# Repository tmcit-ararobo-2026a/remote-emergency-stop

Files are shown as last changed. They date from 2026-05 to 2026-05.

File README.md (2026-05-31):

# Remote Emergency Stop

ロボットなどの遠隔非常停止
920MHzの通信可能

## 目次

1. [概要](#1-概要)
2. [ドキュメント](#2-ドキュメント)
3. [ビルド・使い方](#3-ビルド使い方)
4. [システム構成](#4-システム構成)
5. [ライセンス](#5-ライセンス)

## 1. 概要

<!-- プロジェクトの目的・背景・解決する課題を記述 -->

## 2. ドキュメント

| ドキュメント | 説明 |
| :-: | :-: |
| [CONTRIBUTING.md](./CONTRIBUTING.md) | 開発フロー・コミット規約・コーディング規約 |
| [docs/coding-rules.md](./docs/coding-rules.md) | コーディング規約の詳細 |
| [docs/uml/](./docs/uml/) | UML図 |

## 3. ビルド・使い方

<!-- ビルドのやり方 -->
<!-- 使い方 -->

## 4. システム構成

<!-- ROS2ノード構成・STM32との通信方式・ハードウェア構成 等 -->
<!-- 依存クラスが3つ以上ある場合は docs/uml/ にUML図を作成し、ここにリンクする -->

## 5. ライセンス

本リポジトリは [MITライセンス](./LICENSE) のもとで公開されています。

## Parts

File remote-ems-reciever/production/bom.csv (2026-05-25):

Designator | Footprint | Quantity | Value | LCSC Part #
C1, C4 | 0603 | 2 | 4.7u
C10 | 0603 | 1 | 0.47u
C2, C3, C5, C6, C7, C8, C9 | 0603 | 7 | 0.1u
D1, D2, D3, D4 | 0603 | 4 | LED
IC1 | 114993121 | 1 | Wio-E5
IC2 | SOIC127P600X175-8N | 1 | MCP2562
J1 | SMA_Molex_73251-2120_EdgeMount_Horizontal | 1 | Conn_Coaxial
J2, J3, J5 | JST_XH_S4B-XH-A_1x04_P2.50mm_Horizontal | 3 | Conn_01x04
J4 | PinHeader_1x04_P2.54mm_Vertical | 1 | Conn_01x04_Pin
JP1 | TestPoint_2Pads_Pitch2.54mm_Drill0.8mm | 1 | Jumper_2_Open
Q1 | SOT-23 | 1 | BSS138
R1, R10, R5, R9 | 0603 | 4 | 10k
R11 | 0603 | 1 | 100
R2 | 0603 | 1 | 120
R3, R6, R7, R8 | 0603 | 4 | 1k
R4 | 0603 | 1 | 470
SW1, SW2, SW3 | switch_TVAF06-A020B-R | 3 | SW_Push
SW4 | SW_DIP_SPSTx02_Slide_9.78x7.26mm_W7.62mm_P2.54mm | 1 | SW_DIP_x02
U1 | LQFP-32_7x7mm_P0.8mm | 1 | STM32G431K8Tx
U2 | SOT-23-5_HandSoldering | 1 | NJM12888F33

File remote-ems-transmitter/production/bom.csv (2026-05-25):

Designator | Footprint | Quantity | Value | LCSC Part #
BAR1 | OSX05201-GGR1 | 1 | OSX05201-GGR1
BAR2 | OSX40601-AO | 1 | OSX40601-AO
BT1 | JST_PH_B2B-PH-K_1x02_P2.00mm_Vertical | 1 | Battery_Cell
C1, C4, C8, C9 | 0603 | 4 | 4.7u
C10, C2, C3, C5, C6, C7 | 0603 | 6 | 0.1u
C11 | 0603 | 1 | 0.47u
C12, C13, C14, C15 | 0603 | 4 | 0.1uf
D1, D2 | LED_D5.0mm_FlatTop | 2 | LED
D3 | 0603 | 1 | LED
F1 | 355715 | 1 | Fuse
IC1 | 114993121 | 1 | Wio-E5
J1 | PinHeader_1x04_P2.54mm_Vertical | 1 | Conn_01x04_Pin
J2, J3 | JST_XH_B2B-XH-A_1x02_P2.50mm_Vertical | 2 | Conn_01x02
J4 | SMA_Molex_73251-2120_EdgeMount_Horizontal | 1 | Conn_Coaxial
J5 | USB_C_Receptacle_HRO_TYPE-C-31-M-12 | 1 | USB_C_Receptacle_USB2.0
J6 | PinHeader_1x02_P2.54mm_Vertical | 1 | Conn_01x02_Pin
Q1, Q2 | SOT-23 | 2 | BSS138
R1, R2, R20, R22, R5, R6, R8 | 0603 | 7 | 10k
R10, R11, R12, R13, R14, R15, R16, R17, R18, R4, R9 | 0603 | 11 | 4.7k
R19 | 0603 | 1 | 2k
R21, R3 | 0603 | 2 | 100
R23 | 0603 | 1 | 1k
R7 | 0603 | 1 | 470
SW1, SW2, SW3 | switch_TVAF06-A020B-R | 3 | SW_Push
SW4 | 2MS1-T1-B4-VS2-Q-E-S | 1 | 2MS1-T2-B4-VS2-Q-E-S
U1 | LQFP-32_7x7mm_P0.8mm | 1 | STM32G431K8Tx
U2 | SOT-23-5 | 1 | MCP73831-2-OT
U3 | SOT-23-5_HandSoldering | 1 | NJM12888F33
U4, U5 | SOT-23-5_HandSoldering | 2 | XC8111AA01MR-G

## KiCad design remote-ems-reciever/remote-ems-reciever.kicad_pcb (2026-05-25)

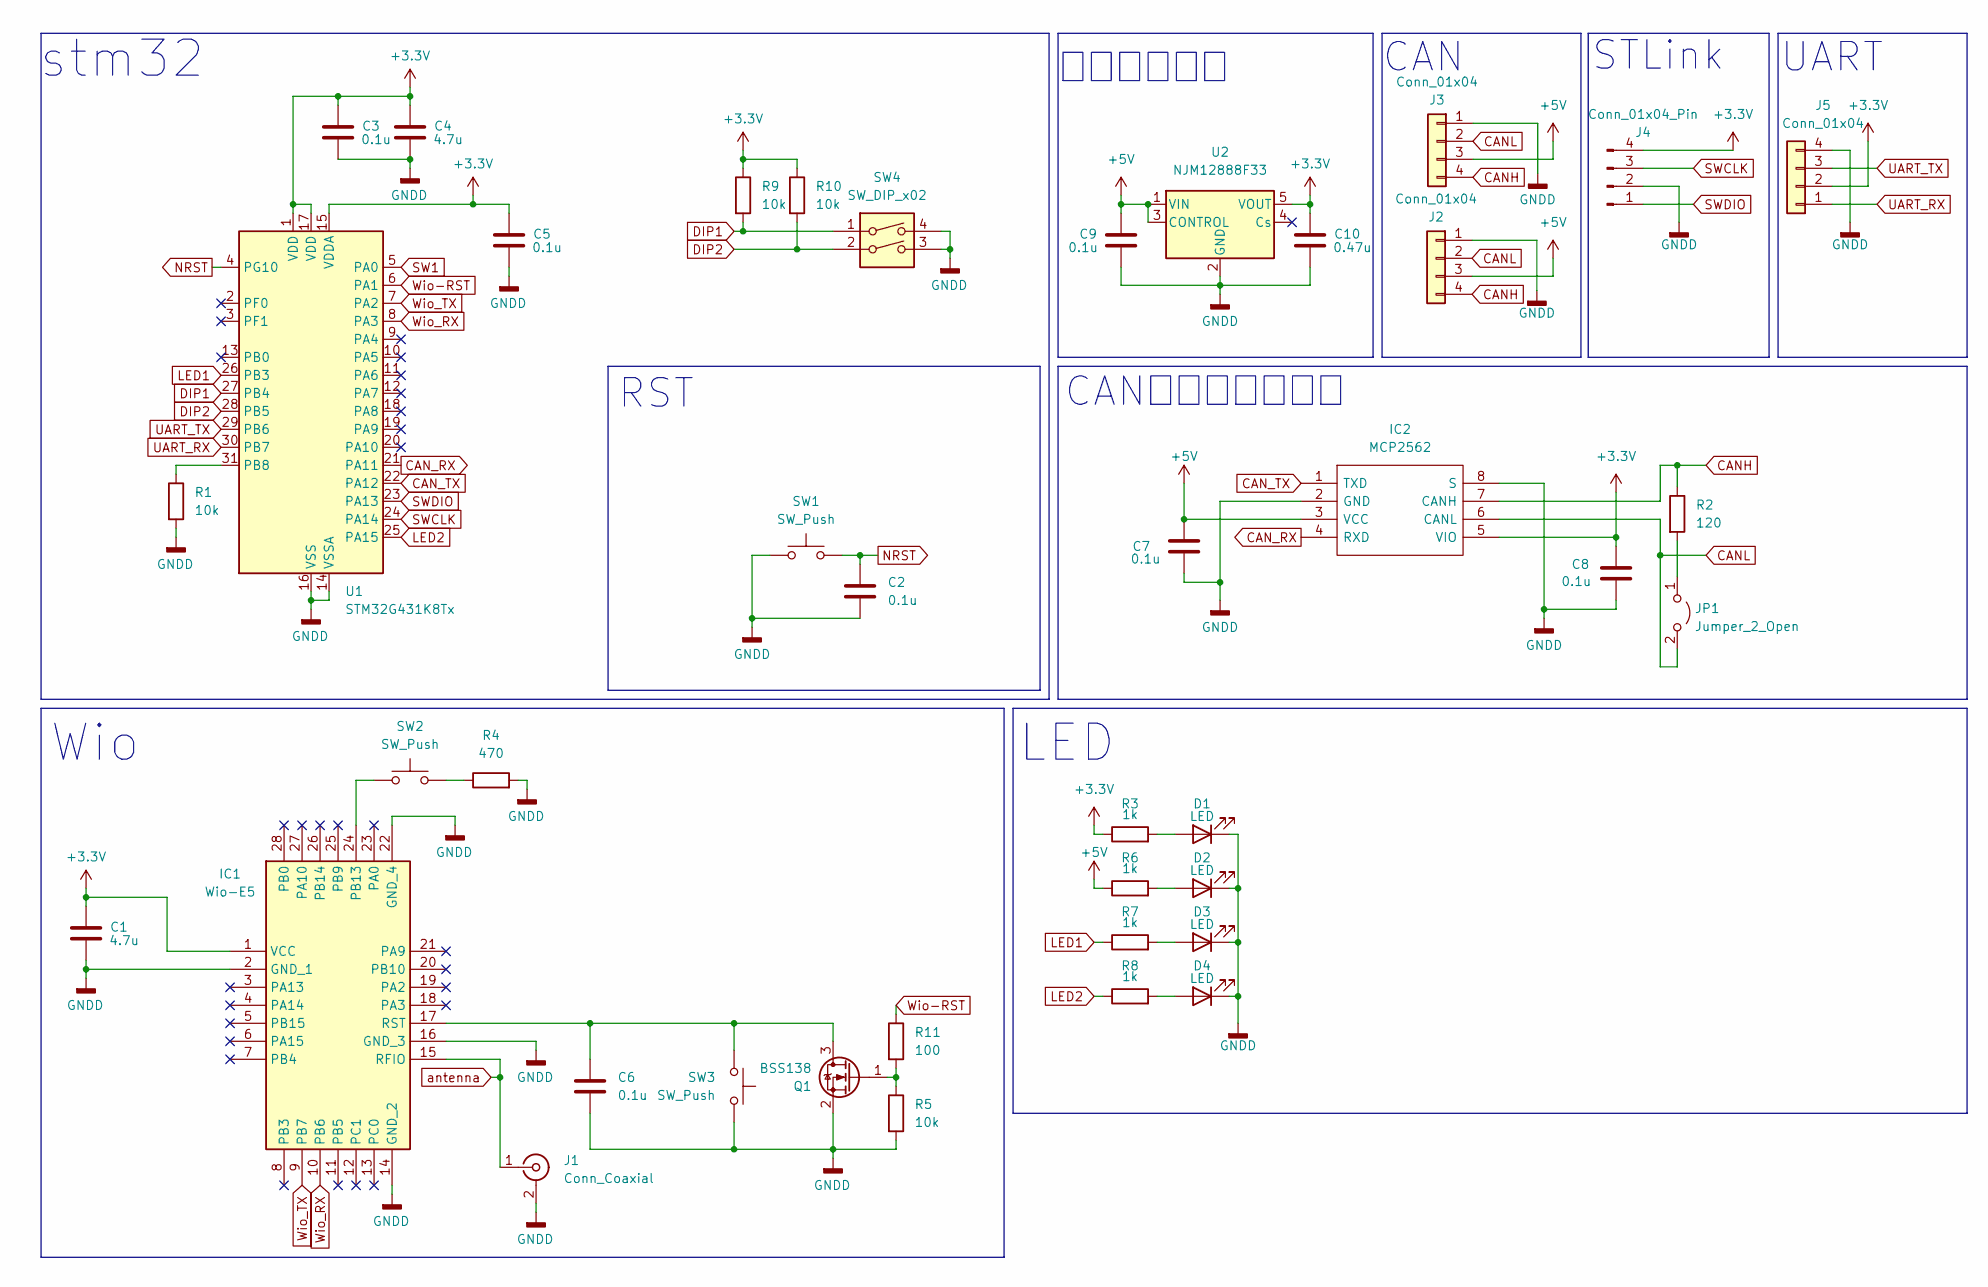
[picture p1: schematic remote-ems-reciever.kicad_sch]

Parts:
C1, C4: 4.7u; C_0603_1608Metric_Pad1.08x0.95mm_HandSolder
C2, C3, C5, C6, C7, C8, C9: 0.1u; C_0603_1608Metric_Pad1.08x0.95mm_HandSolder
C10: 0.47u; C_0603_1608Metric_Pad1.08x0.95mm_HandSolder
D1, D2, D3, D4: LED; LED_0603_1608Metric_Pad1.05x0.95mm_HandSolder
IC1: Wio-E5; 114993121; Mouser Part Number 713-114993121
IC2: MCP2562; SOIC127P600X175-8N; Mouser Part Number 771-TJA1441AT/0Z
J1: Conn_Coaxial; SMA_Molex_73251-2120_EdgeMount_Horizontal
J2, J3, J5: Conn_01x04; JST_XH_S4B-XH-A_1x04_P2.50mm_Horizontal
J4: Conn_01x04_Pin; PinHeader_1x04_P2.54mm_Vertical
JP1: Jumper_2_Open; TestPoint_2Pads_Pitch2.54mm_Drill0.8mm
Q1: BSS138; SOT-23
R1, R5, R9, R10: 10k; R_0603_1608Metric_Pad0.98x0.95mm_HandSolder
R2: 120; R_0603_1608Metric_Pad0.98x0.95mm_HandSolder
R3, R6, R7, R8: 1k; R_0603_1608Metric_Pad0.98x0.95mm_HandSolder
R4: 470; R_0603_1608Metric_Pad0.98x0.95mm_HandSolder
R11: 100; R_0603_1608Metric_Pad0.98x0.95mm_HandSolder
SW1, SW2, SW3: SW_Push; switch_TVAF06-A020B-R
SW4: SW_DIP_x02; SW_DIP_SPSTx02_Slide_9.78x7.26mm_W7.62mm_P2.54mm
U1: STM32G431K8Tx; LQFP-32_7x7mm_P0.8mm
U2: NJM12888F33; SOT-23-5_HandSoldering

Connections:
+3.3V: C1.1, C3.1, C4.1, C5.1, C8.1, C10.1, IC1.1 (VCC), IC2.5 (VIO), J4.4, J5.2, R3.1, R9.1, R10.1, U1.1 (VDD), U1.15 (VDDA), U1.17 (VDD), U2.5 (VOUT)
+5V: C7.1, C9.1, IC2.3 (VCC), J2.3, J3.3, R6.1, U2.1 (VIN), U2.3 (CONTROL)
CANH: IC2.7 (CANH), J2.4, J3.4, R2.1
CANL: IC2.6 (CANL), J2.2, J3.2, JP1.2 (B)
CAN_RX: IC2.4 (RXD), U1.21 (PA11)
CAN_TX: IC2.1 (TXD), U1.22 (PA12)
DIP1: R9.2, SW4.1, U1.27 (PB4)
DIP2: R10.2, SW4.2, U1.28 (PB5)
GNDD: C1.2, C2.2, C3.2, C4.2, C5.2, C6.2, C7.2, C8.2, C9.2, C10.2, D1.1 (K), D2.1 (K), D3.1 (K), D4.1 (K), IC1.2 (GND_1), IC1.14 (GND_2), IC1.16 (GND_3), IC1.22 (GND_4), IC2.2 (GND), IC2.8 (S), J1.2 (Ext), J2.1, J3.1, J4.2, J5.4, Q1.2 (S), R1.2, R4.2, R5.2, SW1.1, SW3.1, SW4.3, SW4.4, U1.14 (VSSA), U1.16 (VSS), U1.32 (VSS), U2.2 (GND)
LED1: R7.1, U1.26 (PB3)
LED2: R8.1, U1.25 (PA15)
NRST: C2.1, SW1.2, U1.4 (PG10)
unnamed: D1.2 (A), R3.2
unnamed: D2.2 (A), R6.2
unnamed: D3.2 (A), R7.2
unnamed: D4.2 (A), R8.2
unnamed: IC1.24 (PB13), SW2.2
unnamed: C6.1, IC1.17 (RST), Q1.3 (D), SW3.2
unnamed: JP1.1 (A), R2.2
unnamed: Q1.1 (G), R5.1, R11.2
unnamed: R4.1, SW2.1
unnamed: R1.1, U1.31 (PB8)
SW1: U1.5 (PA0)
SWCLK: J4.3, U1.24 (PA14)
SWDIO: J4.1, U1.23 (PA13)
UART_RX: J5.1, U1.30 (PB7)
UART_TX: J5.3, U1.29 (PB6)
Wio-RST: R11.1, U1.6 (PA1)
Wio_RX: IC1.10 (PB6), U1.8 (PA3)
Wio_TX: IC1.9 (PB7), U1.7 (PA2)
antenna: IC1.15 (RFIO), J1.1 (In)

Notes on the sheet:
CAN
Wio
RST
CANトランシーバー
レギュレータ
UART
stm32
LED
STLink

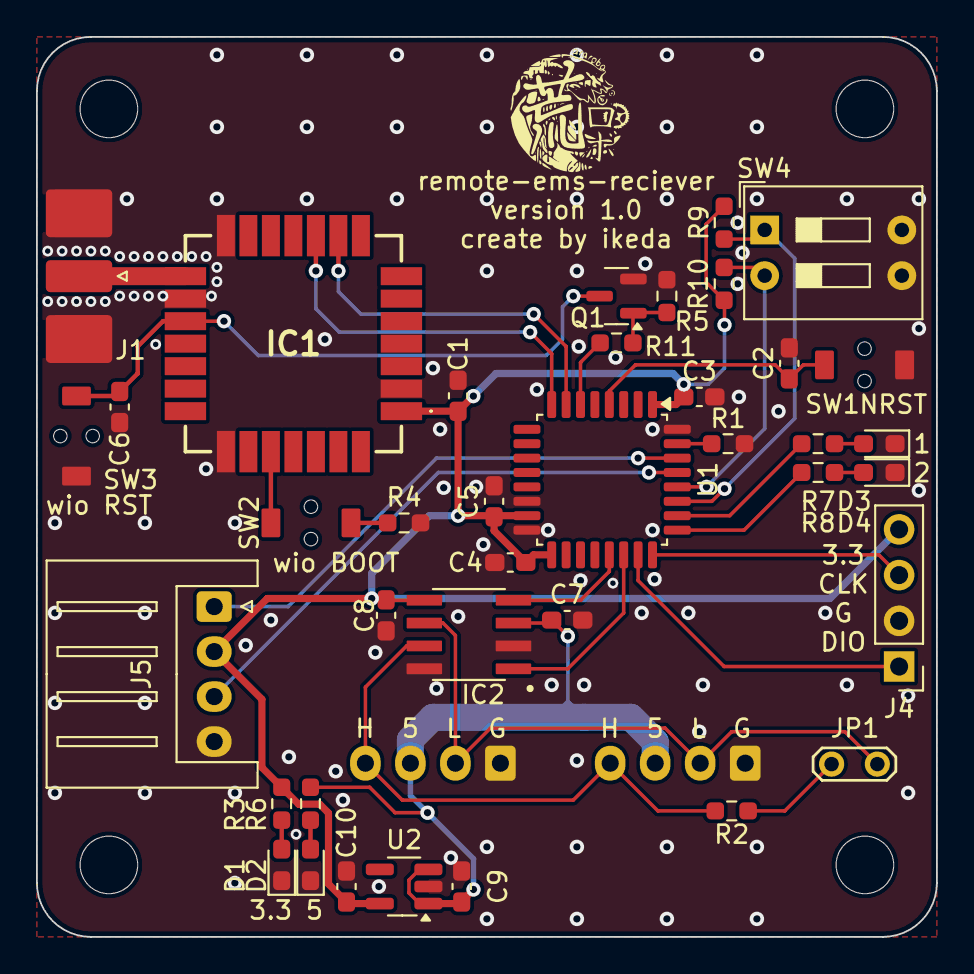
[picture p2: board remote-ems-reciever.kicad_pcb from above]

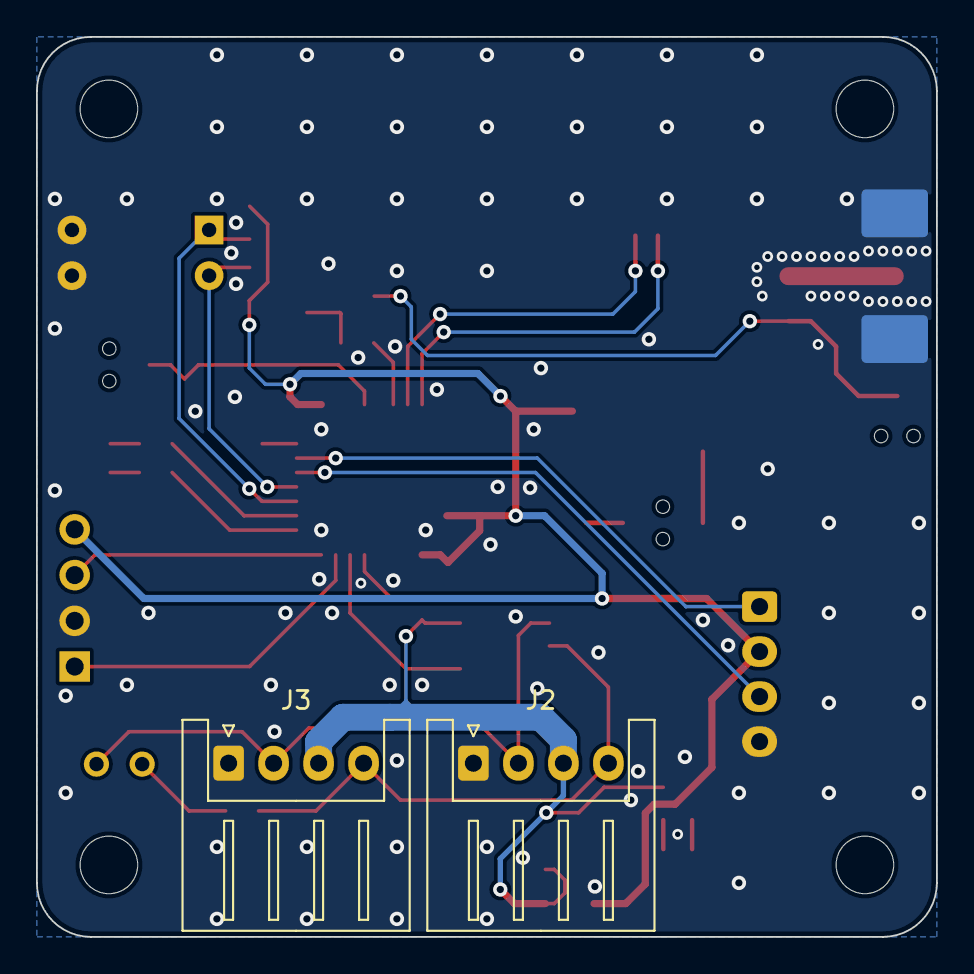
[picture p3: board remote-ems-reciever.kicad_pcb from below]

Board: 2 copper layers, 50.0 x 50.0 mm, 40 parts (2 on the bottom side), 30 nets.

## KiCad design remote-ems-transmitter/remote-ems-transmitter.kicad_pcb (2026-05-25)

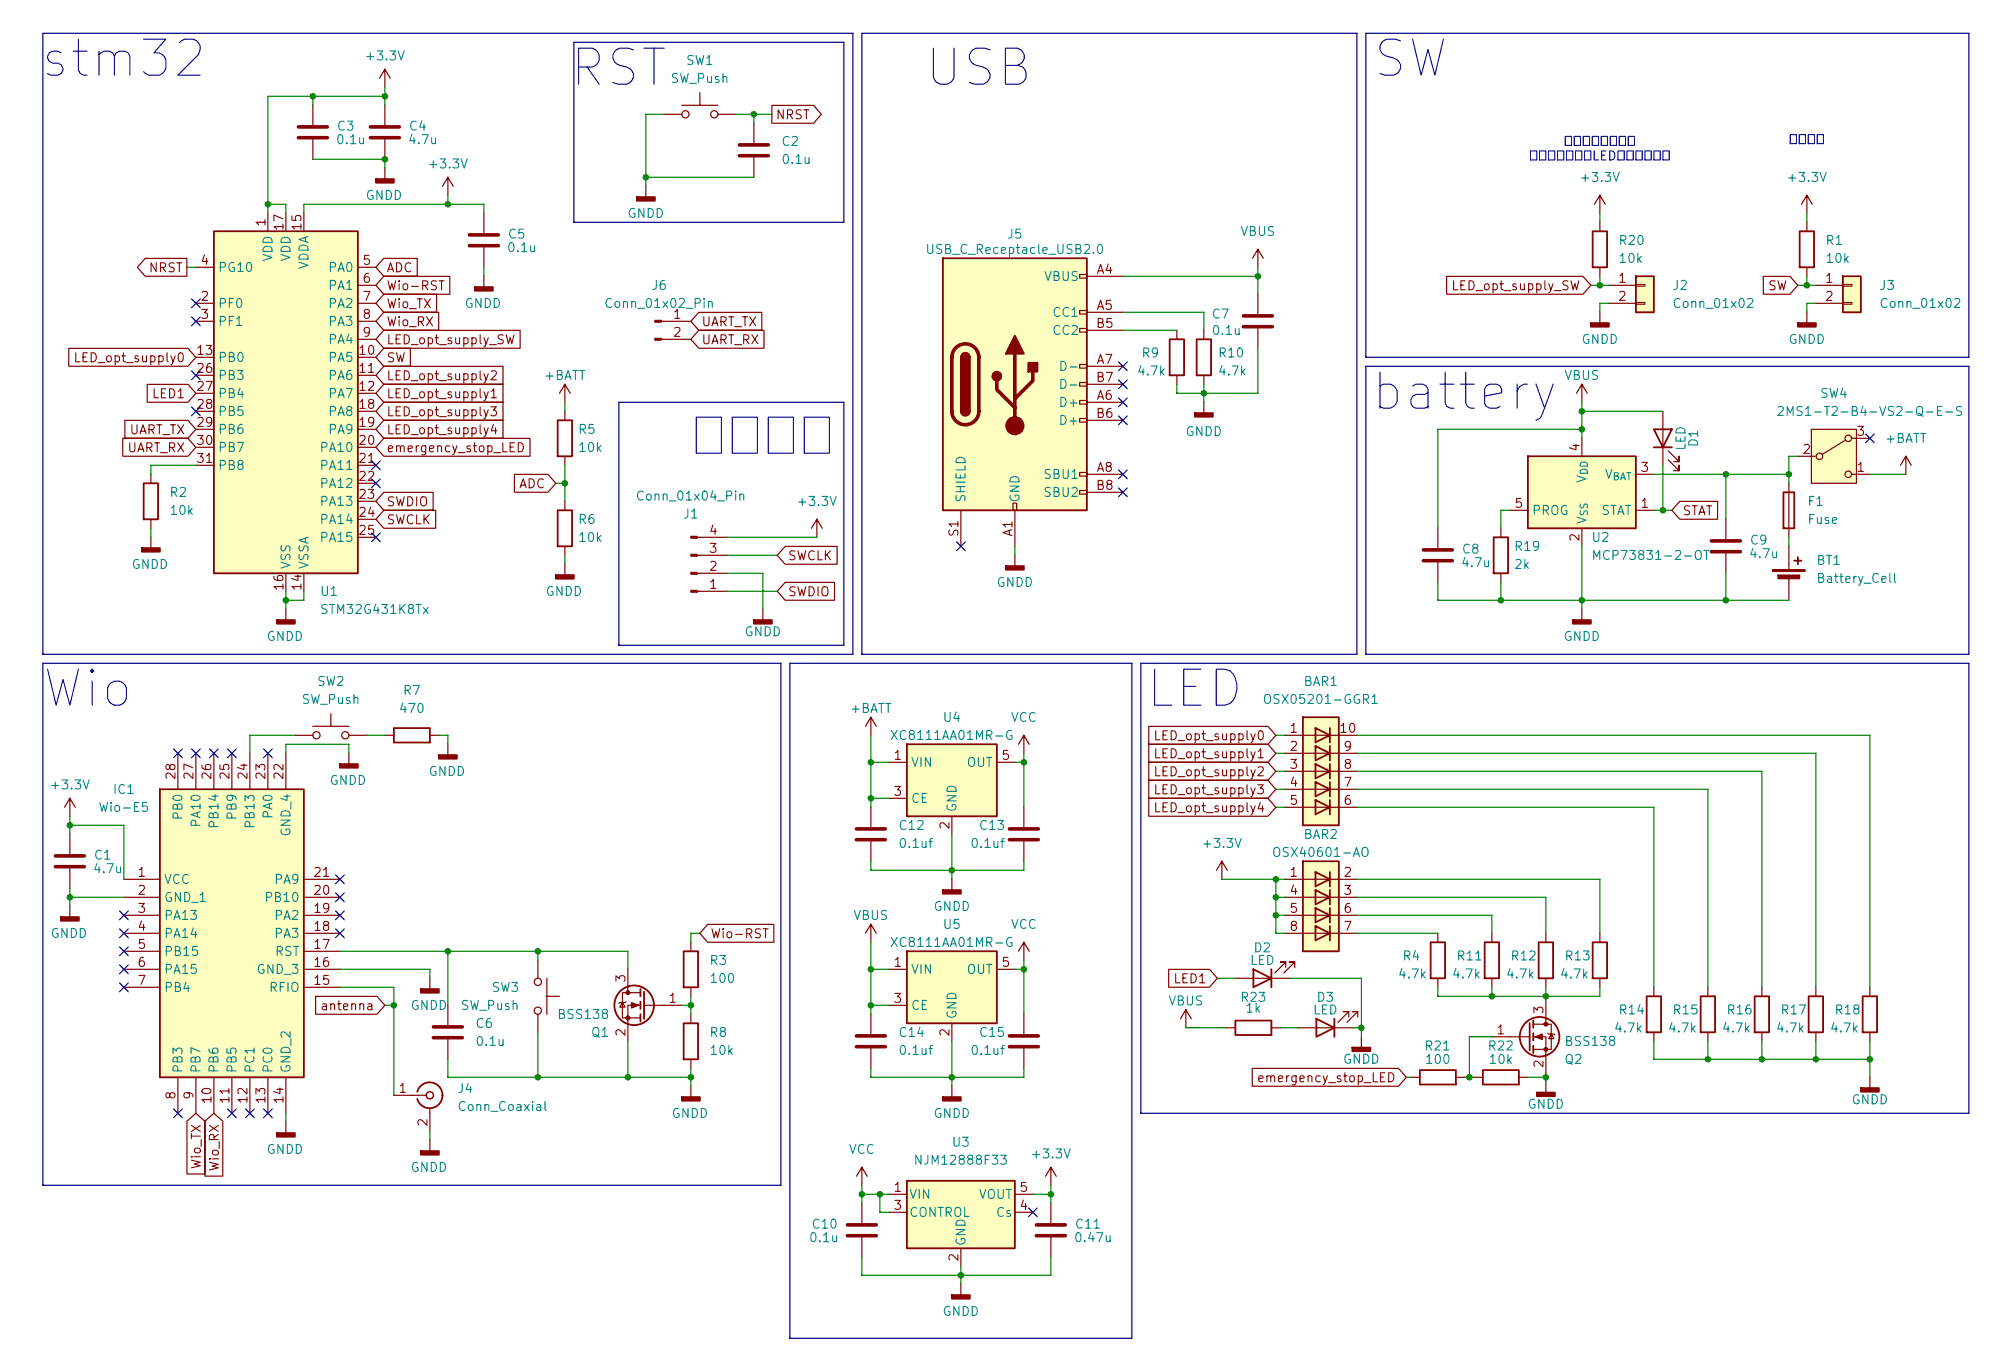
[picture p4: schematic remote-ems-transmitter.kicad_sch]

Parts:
BAR1: OSX05201-GGR1
BAR2: OSX40601-AO
BT1: Battery_Cell; JST_PH_B2B-PH-K_1x02_P2.00mm_Vertical
C1, C4, C8, C9: 4.7u; C_0603_1608Metric_Pad1.08x0.95mm_HandSolder
C2, C3, C5, C6, C7, C10: 0.1u; C_0603_1608Metric_Pad1.08x0.95mm_HandSolder
C11: 0.47u; C_0603_1608Metric_Pad1.08x0.95mm_HandSolder
C12, C13, C14, C15: 0.1uf; C_0603_1608Metric_Pad1.08x0.95mm_HandSolder
D1, D2: LED; LED_D5.0mm_FlatTop
D3: LED; LED_0603_1608Metric_Pad1.05x0.95mm_HandSolder
F1: Fuse; 355715
IC1: Wio-E5; 114993121; Mouser Part Number 713-114993121
J1: Conn_01x04_Pin; PinHeader_1x04_P2.54mm_Vertical
J2, J3: Conn_01x02; JST_XH_B2B-XH-A_1x02_P2.50mm_Vertical
J4: Conn_Coaxial; SMA_Molex_73251-2120_EdgeMount_Horizontal
J5: USB_C_Receptacle_USB2.0; USB_C_Receptacle_HRO_TYPE-C-31-M-12
J6: Conn_01x02_Pin; PinHeader_1x02_P2.54mm_Vertical
Q1, Q2: BSS138; SOT-23
R1, R2, R5, R6, R8, R20, R22: 10k; R_0603_1608Metric_Pad0.98x0.95mm_HandSolder
R3, R21: 100; R_0603_1608Metric_Pad0.98x0.95mm_HandSolder
R4, R9, R10, R11, R12, R13, R14, R15, R16, R17, R18: 4.7k; R_0603_1608Metric_Pad0.98x0.95mm_HandSolder
R7: 470; R_0603_1608Metric_Pad0.98x0.95mm_HandSolder
R19: 2k; R_0603_1608Metric_Pad0.98x0.95mm_HandSolder
R23: 1k; R_0603_1608Metric_Pad0.98x0.95mm_HandSolder
SW1, SW2, SW3: SW_Push; switch_TVAF06-A020B-R
SW4: 2MS1-T2-B4-VS2-Q-E-S; 2MS1-T1-B4-VS2-Q-E-S
U1: STM32G431K8Tx; LQFP-32_7x7mm_P0.8mm
U2: MCP73831-2-OT; SOT-23-5
U3: NJM12888F33; SOT-23-5_HandSoldering
U4, U5: XC8111AA01MR-G; SOT-23-5_HandSoldering

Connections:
+3.3V: BAR2.1 (A), BAR2.4 (A), BAR2.5 (A), BAR2.8 (K), C1.1, C3.1, C4.1, C5.1, C11.1, IC1.1 (VCC), J1.4, R1.1, R20.1, U1.1 (VDD), U1.15 (VDDA), U1.17 (VDD), U3.5 (VOUT)
+BATT: C12.1, R5.1, SW4.1 (C), U4.1 (VIN), U4.3 (CE)
ADC: R5.2, R6.1, U1.5 (PA0)
GNDD: BT1.2 (-), C1.2, C2.2, C3.2, C4.2, C5.2, C6.2, C7.2, C8.2, C9.2, C10.2, C11.2, C12.2, C13.2, C14.2, C15.2, D2.1 (K), D3.1 (K), IC1.2 (GND_1), IC1.14 (GND_2), IC1.16 (GND_3), IC1.22 (GND_4), J1.2, J2.2, J3.2, J4.2 (Ext), J5.A1 (GND), J5.A12 (GND), J5.B1 (GND), J5.B12 (GND), Q1.2 (S), Q2.2 (S), R2.2, R6.2, R7.2, R8.2, R9.2, R10.2, R14.2, R15.2, R16.2, R17.2, R18.2, R19.2, R22.2, SW1.1, SW3.1, U1.14 (VSSA), U1.16 (VSS), U1.32 (VSS), U2.2 (V_{SS}), U3.2 (GND), U4.2 (GND), U5.2 (GND)
LED1: D2.2 (A), U1.27 (PB4)
LED_opt_supply0: BAR1.1 (A), U1.13 (PB0)
LED_opt_supply1: BAR1.2 (A), U1.12 (PA7)
LED_opt_supply2: BAR1.3 (A), U1.11 (PA6)
LED_opt_supply3: BAR1.4 (A), U1.18 (PA8)
LED_opt_supply4: BAR1.5 (A), U1.19 (PA9)
LED_opt_supply_SW: J2.1, R20.2, U1.9 (PA4)
NRST: C2.1, SW1.2, U1.4 (PG10)
unnamed: BAR1.6 (K), R14.1
unnamed: BAR1.7 (K), R15.1
unnamed: BAR1.8 (K), R16.1
unnamed: BAR1.9 (K), R17.1
unnamed: BAR1.10 (K), R18.1
unnamed: BAR2.2 (A), R13.1
unnamed: BAR2.3 (A), R12.1
unnamed: BAR2.6 (K), R11.1
unnamed: BAR2.7 (K), R4.1
unnamed: BT1.1 (+), F1.2
unnamed: D3.2 (A), R23.2
unnamed: IC1.24 (PB13), SW2.2
unnamed: C6.1, IC1.17 (RST), Q1.3 (D), SW3.2
unnamed: J5.A5 (CC1), R10.1
unnamed: J5.B5 (CC2), R9.1
unnamed: Q1.1 (G), R3.2, R8.1
unnamed: Q2.3 (D), R4.2, R11.2, R12.2, R13.2
unnamed: Q2.1 (G), R21.2, R22.1
unnamed: R7.1, SW2.1
unnamed: C9.1, F1.1, SW4.2 (B), U2.3 (V_{BAT})
unnamed: R2.1, U1.31 (PB8)
unnamed: R19.1, U2.5 (PROG)
STAT: D1.1 (K), U2.1 (STAT)
SW: J3.1, R1.2, U1.10 (PA5)
SWCLK: J1.3, U1.24 (PA14)
SWDIO: J1.1, U1.23 (PA13)
UART_RX: J6.2, U1.30 (PB7)
UART_TX: J6.1, U1.29 (PB6)
VBUS: C7.1, C8.1, C14.1, D1.2 (A), J5.A4 (VBUS), J5.A9 (VBUS), J5.B4 (VBUS), J5.B9 (VBUS), R23.1, U2.4 (V_{DD}), U5.1 (VIN), U5.3 (CE)
VCC: C10.1, C13.1, C15.1, U3.1 (VIN), U3.3 (CONTROL), U4.5 (OUT), U5.5 (OUT)
Wio-RST: R3.1, U1.6 (PA1)
Wio_RX: IC1.10 (PB6), U1.8 (PA3)
Wio_TX: IC1.9 (PB7), U1.7 (PA2)
antenna: IC1.15 (RFIO), J4.1 (In)
emergency_stop_LED: R21.1, U1.20 (PA10)

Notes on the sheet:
USB
書き込み
battery
stm32
Wio
LED
バッテリー残量用 押すと数秒だけLEDアレイが光る
RST
非常停止

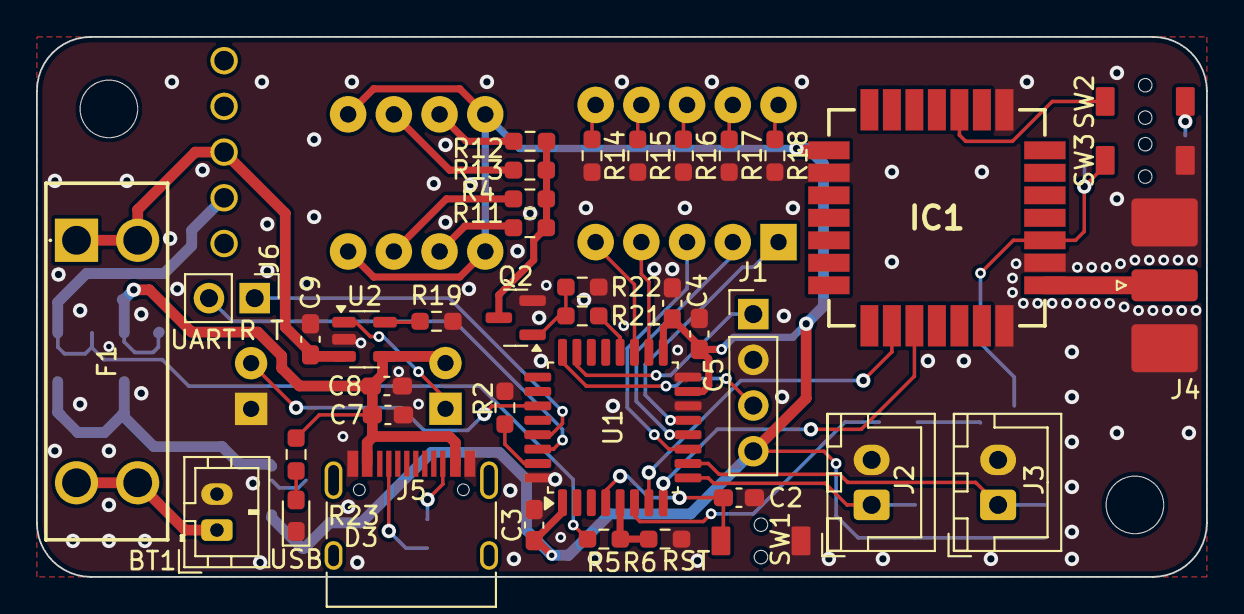
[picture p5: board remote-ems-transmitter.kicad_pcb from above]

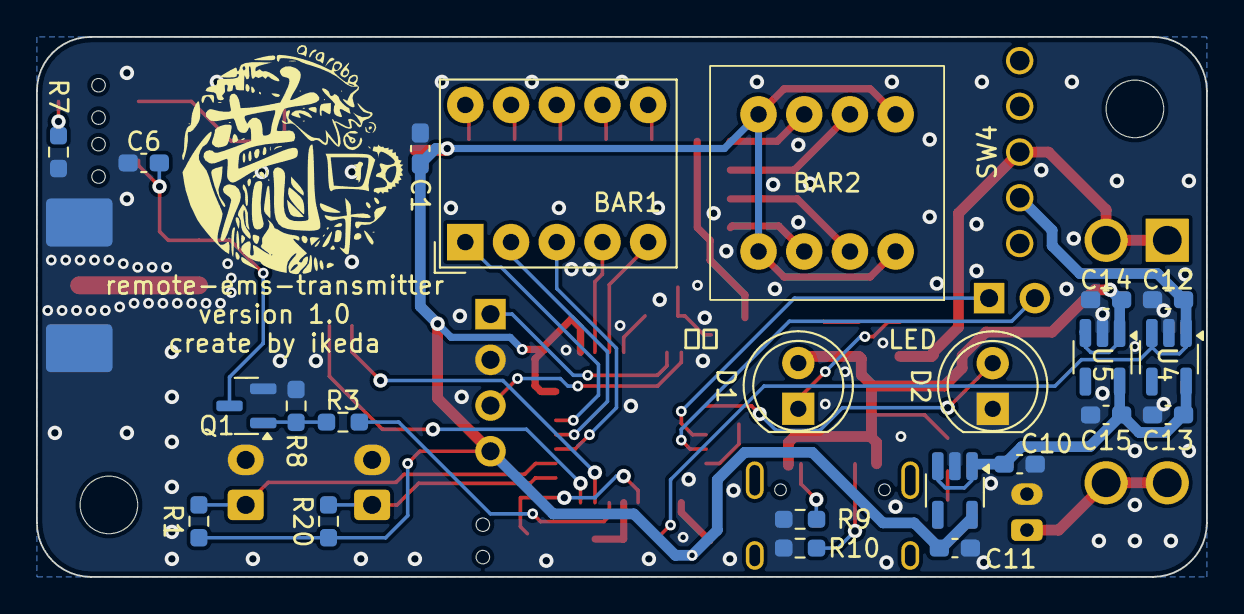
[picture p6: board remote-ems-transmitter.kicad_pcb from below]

Board: 2 copper layers, 65.0 x 30.0 mm, 63 parts (24 on the bottom side), 47 nets.

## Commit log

2026-05-16 回路図完成 LED等の一部はまだ
    [remote-ems-reciever.kicad_pcb, remote-ems-reciever.kicad_sch, remote-ems-transmitter.kicad_pcb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]
2026-05-17 remote-ems-transmitter ビア、シルク、LED以外完成
    [remote-ems-reciever.kicad_pcb, remote-ems-reciever.kicad_sch, remote-ems-transmitter.kicad_pcb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]
2026-05-17 remote-ems-reciever ビア、シルク、LED以外完成
    [remote-ems-reciever.kicad_pcb, remote-ems-reciever.kicad_sch]
2026-05-17 LED周り修正
    [remote-ems-transmitter.kicad_pcb, remote-ems-transmitter.kicad_sch]
2026-05-19 LED仕様変更
    [remote-ems-transmitter.kicad_pcb, remote-ems-transmitter.kicad_sch]
2026-05-21 ビア打ち、シルク修正中 残りは別日に対応します
    [remote-ems-reciever.kicad_pcb, remote-ems-transmitter.kicad_pcb, remote-ems-transmitter.kicad_sch]
2026-05-25 FETの向きを修正 ガーバー出力
    [bom.csv, designators.csv, positions.csv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]
